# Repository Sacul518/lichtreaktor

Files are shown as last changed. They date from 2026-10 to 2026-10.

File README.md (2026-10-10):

# Lichtreaktor

I'm designing a small, round arc-reactor lookalike that produces light in cool patterns. The plan is to press the rotary encoder to switch patterns, and turn it to control the brightness.

The PCB is 90 mm across, with 24 blue LEDs around the edge, a knob in the middle and a XIAO near the top for USB-C access. Six groups of four LEDs will be controlled independently. Tiny reactor, zero fusion involved.

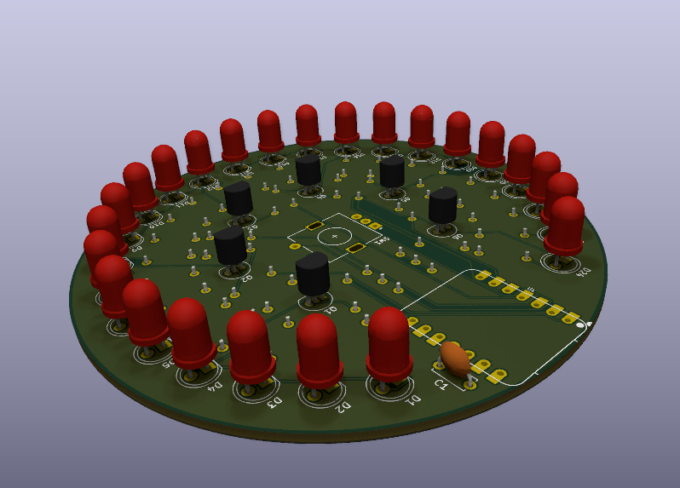
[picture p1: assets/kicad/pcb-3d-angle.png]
Angled view of the Lichtreaktor PCB in KiCad's 3D viewer


The LEDs look red in KiCad's default 3D model, but the actual parts are blue. The XIAO and rotary encoder don't have 3D models loaded, so their positions look empty here.

## Where it's at

The schematic and PCB layout are done! All 24 LEDs are placed, the traces are routed, and both copper layers have a GND fill. The LEDs, transistors, encoder and XIAO sit on the front; the resistors sit on the back. Getting everything onto a round board took a few attempts, but it fits.

The latest KiCad check (10 October 2026) reports **0 errors, 0 unconnected items and 0 schematic/PCB mismatches**. There are still 24 silkscreen warnings: some printed outlines or labels overlap pads, each other or the board edge. Those are accepted for this layout; parts of the print may be clipped during manufacturing. The USB connector intentionally sticks out a little at the top.

This is still a design, not a tested reactor. The [firmware](firmware/README.md) is written, with five light patterns, encoder controls, adjustable speed, a group test and USB diagnostics. Final part and mechanical checks, supplier prices, fabrication files, soldering and testing on the actual board are next.

## How it works

USB supplies 5 V through the XIAO. Each LED has its own 220 Ω resistor, and each group of four shares a BC337 transistor that switches its connection to GND. The XIAO drives the six transistors through 470 Ω base resistors; 100 kΩ pull-downs keep them off when the control pins aren't being driven. PWM will let the firmware dim each group separately.

The encoder has two rotation signals and a push button, with three 10 kΩ pull-ups to 3.3 V. Turning it will change the brightness, and pressing it will change the pattern. The GND fills keep clearance from the other nets and use thermal reliefs so the pads are easier to hand-solder.

## What will I need to build this?

- Seeed Studio XIAO RP2040 (same one I used for my super cool and sick Hackpad)
- 24 blue LEDs (WP7113QBD/D) (ChatGPT's favourites)
- 24 LED resistors (220 Ω, 1/4 W), one per LED
- A PCB (self-designed ofc)
- 6 BC337 NPN transistors, one per group of four LEDs
- 6 transistor base resistors (470 Ω, 1/4 W)
- 6 transistor pull-down resistors (100 kΩ, 1/4 W)
- Alps Alpine EC11E18244A5 rotary encoder with push button
- 3 encoder pull-up resistors (10 kΩ, 1/4 W)
- 100 nF ceramic capacitor (at least 25 V)
- 2 seven-pin female headers (2.54 mm pitch) for the XIAO
- 2 matching male headers, if the XIAO doesn't already have them
- USB cable for power and programming through the XIAO's USB-C port

[Design BOM with KiCad symbols and footprints](bom.csv). Exact resistor, capacitor and header parts, supplier prices and final mechanical checks are still pending.

## Why these LED coordinates?

The numbers aren't random, even if typing them into KiCad feels a bit like it. The board has a 45 mm radius; the LED centres follow a smaller circle with a 38 mm radius. Its centre is at $(x_c,y_c)=(185,65)\,\mathrm{mm}$ in the PCB editor, right on the encoder shaft.

The planned ring starts 30 degrees clockwise from the top, with 13 degrees between neighbouring LEDs. For LED number $n$, from 1 to 24:

$$
\theta_n = 30^\circ + (n-1)\cdot 13^\circ
$$

The last LED lands at 329 degrees. That leaves a 61-degree gap across the top for the XIAO and USB connection. These angles are layout choices; the circle formula gives the coordinates from them.

KiCad's Y coordinate increases downwards. Measuring the angle clockwise from the top gives:

$$
x_{\mathrm{centre},n}=185\,\mathrm{mm}+38\,\mathrm{mm}\cdot\sin(\theta_n)
$$

$$
y_{\mathrm{centre},n}=65\,\mathrm{mm}-38\,\mathrm{mm}\cdot\cos(\theta_n)
$$

One small catch: the `LED_THT:LED_D5.0mm` footprint is anchored on pad 1, with the LED centre 1.27 mm to its right at 0-degree rotation. So the positions entered in KiCad are:

$$
x_{\mathrm{KiCad},n}=x_{\mathrm{centre},n}-1.27\,\mathrm{mm},\qquad
y_{\mathrm{KiCad},n}=y_{\mathrm{centre},n}
$$

For D1, $\theta_1=30^\circ$, which gives:

$$
x_{\mathrm{KiCad},1}=185+38\sin(30^\circ)-1.27=202.73\,\mathrm{mm}
$$

$$
y_{\mathrm{KiCad},1}=65-38\cos(30^\circ)\approx32.09\,\mathrm{mm}
$$

All LEDs use 0-degree rotation for this calculation, and coordinates are rounded to 0.01 mm. Neighbouring LED centres are about $2\cdot38\sin(13^\circ/2)=8.60\,\mathrm{mm}$ apart. Some resistor positions were adjusted by hand to avoid overlaps; the final layout passes KiCad's copper-clearance and courtyard checks.

## Design files

Open [the KiCad project](hardware/Lichtreaktor/Lichtreaktor.kicad_pro) to see the schematic and PCB. The project includes its XIAO symbol and footprint libraries; their source and adaptations are documented [here](hardware/Lichtreaktor/libraries/SOURCES.md).

## A closer look

### PCB layout

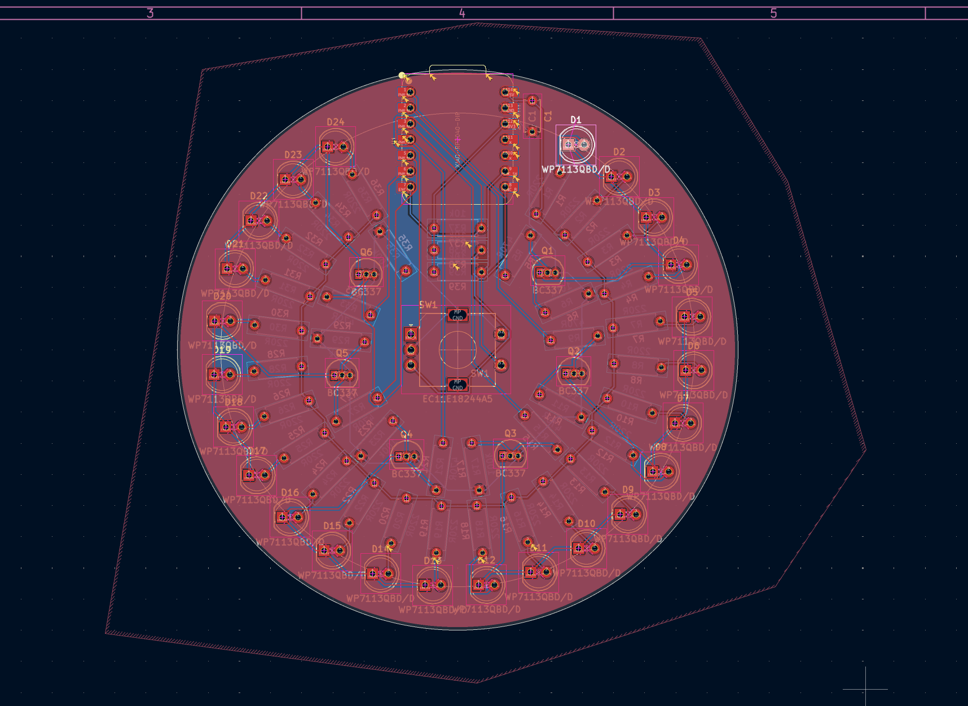
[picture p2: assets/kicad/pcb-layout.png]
Routed PCB layout with GND fills in KiCad


### Front and back

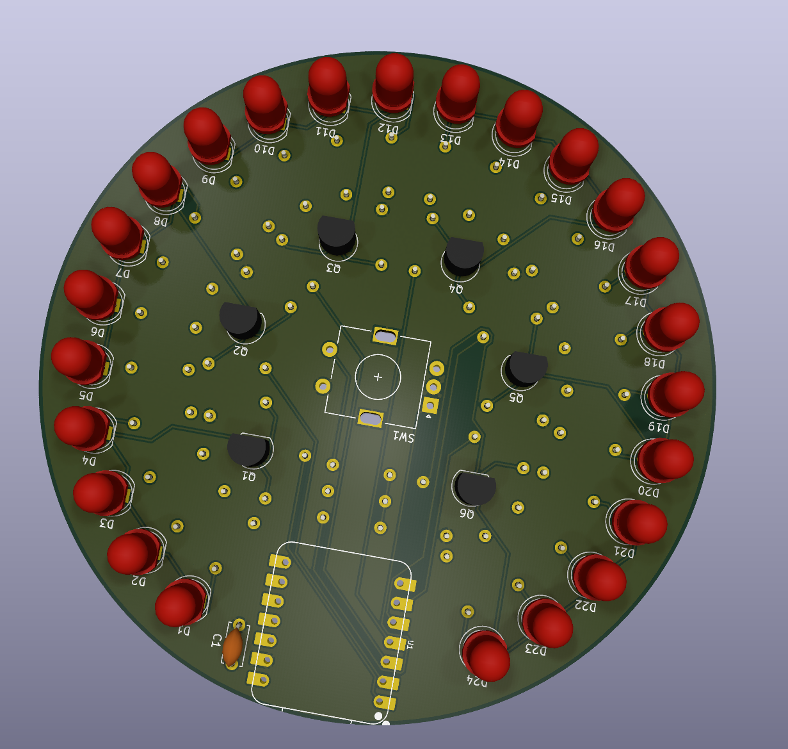
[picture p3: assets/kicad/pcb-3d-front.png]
Front of the PCB in KiCad's 3D viewer


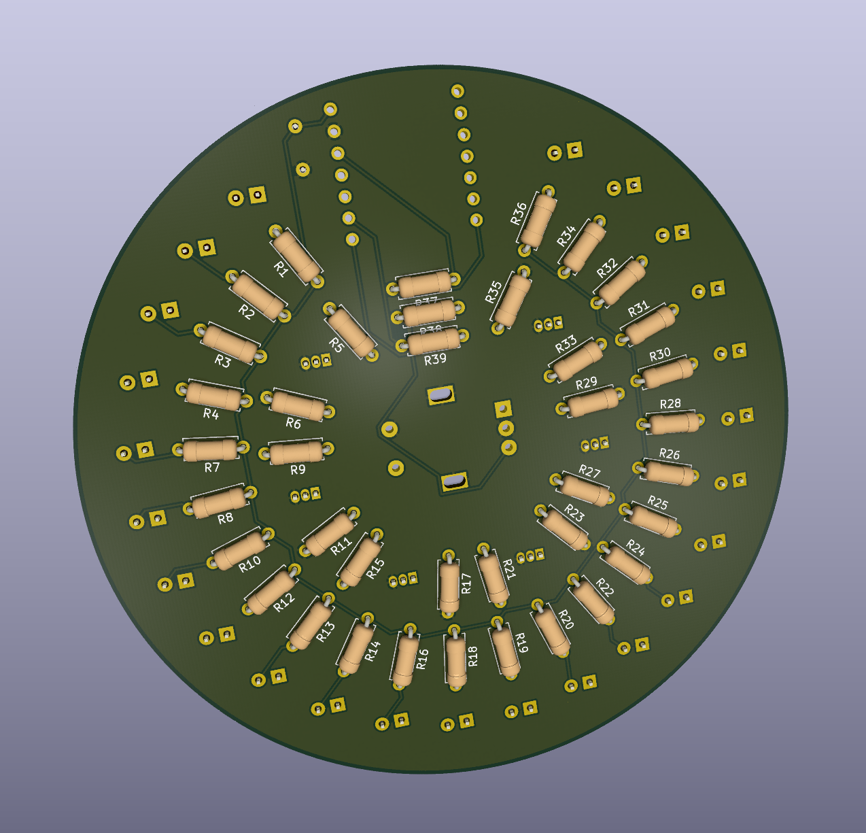
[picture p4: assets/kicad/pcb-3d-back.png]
Back of the PCB with the resistors in KiCad's 3D viewer


### Schematic

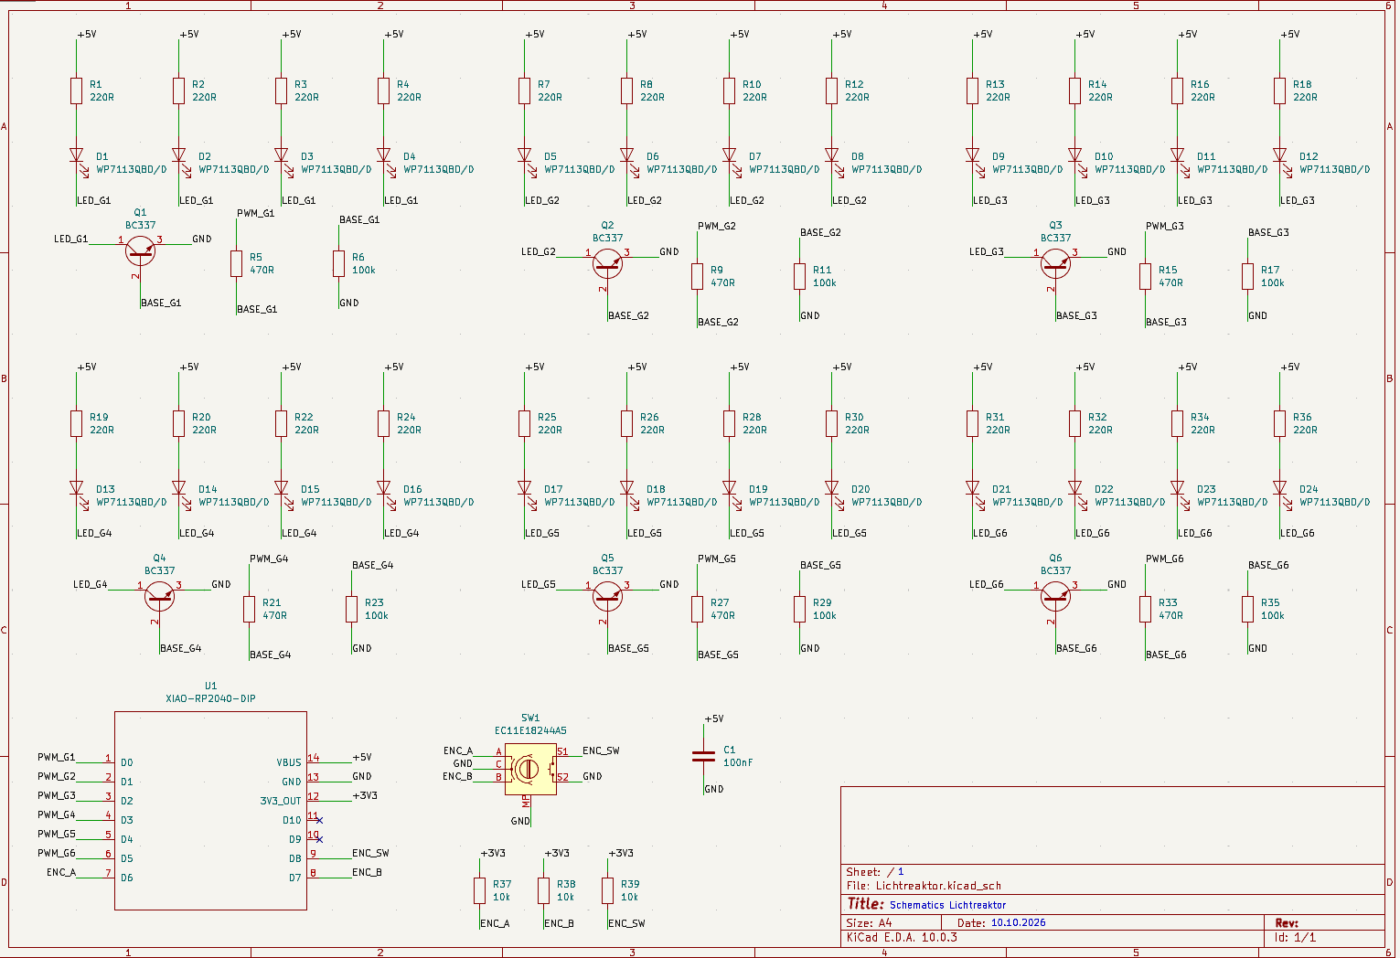
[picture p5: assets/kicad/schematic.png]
Complete Lichtreaktor schematic with six LED groups and the XIAO RP2040


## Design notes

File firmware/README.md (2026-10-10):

# Lichtreaktor firmware

Arduino C++ for the **Seeed XIAO RP2040**, using Earle Philhower's **Arduino-Pico 6.3.0** core. No additional libraries are required.

## Controls

- Turn the encoder to change brightness in steps of 8, from 0 (off) to 255.
- Press and release to cycle through steady light, breathing, a rotating trail, alternating groups and a double pulse.
- Hold and turn to change effect speed from 25% to 300% in steps of 25%. A speed change restarts the current effect. Release without changing the pattern.
- Hold for 1.2 seconds without turning to enter or leave the LED group test. In the test, turning selects one of the six groups; a short press leaves the test. Brightness is retained, so turn it up before entering if it is currently zero.
- Starts in steady mode at brightness 80/255. Settings reset when power is removed.

The encoder is polled continuously, the button is debounced for 25 ms, and LED values are recalculated and written on every loop without blocking delays. PWM runs at 2 kHz. All LEDs within a group share the same output; this board cannot control individual LEDs separately.

## USB diagnostics

Open a serial monitor at 115200 baud. USB serial is optional; the board does not wait for a computer to connect. Commands are single characters, so a newline is not required (and is ignored).

| Command | Action |
| --- | --- |
| `?` | Show command help |
| `s` | Show pattern, brightness, speed, test mode and selected group |
| `n` | Next pattern and leave test mode |
| `+` / `-` | Increase / decrease brightness |
| `>` / `<` | Increase / decrease speed |
| `t` | Toggle the group test, starting at group 1 |
| `1` through `6` | Enter the test and select that LED group |

Pattern and group numbers in the status output start at 1. Only the selected group lights in test mode. For example, send `1`, then `2`, through `6` to check each transistor and its four LEDs. If brightness is zero, use `+` to raise it. `n` returns to an effect. USB processing is limited to eight incoming characters per loop, and pending replies wait for output buffer space.

Codex helped write the firmware; comments in the sketch identify that assistance. Hardware validation is still pending.

## Pin mapping

Arduino-Pico's raw pin numbers are the RP2040 GPIO numbers. They are **not** the D numbers printed on the module.

| PCB signal | XIAO pin | GPIO used in firmware |
| --- | --- | --- |
| PWM_G1 | D0 | 26 |
| PWM_G2 | D1 | 27 |
| PWM_G3 | D2 | 28 |
| PWM_G4 | D3 | 29 |
| PWM_G5 | D4 | 6 |
| PWM_G6 | D5 | 7 |
| ENC_A | D6 | 0 |
| ENC_B | D7 | 1 |
| ENC_SW | D8 | 2 |

The encoder inputs use the PCB's external 10 kΩ pull-ups to 3.3 V. LED outputs are active high because the BC337 transistors switch the groups to GND.

The EC11E18244A5 has 36 detents and 18 pulses per revolution, so `ENCODER_TRANSITIONS_PER_STEP` is 2. For an encoder substitute, check its datasheet. If clockwise rotation dims instead of brightening, change `ENCODER_DIRECTION` from `1` to `-1` and rebuild.

## Build

Install [Arduino CLI](https://docs.arduino.cc/arduino-cli/installation), then run these commands from the repository root:

```sh
arduino-cli core update-index --additional-urls https://github.com/earlephilhower/arduino-pico/releases/download/global/package_rp2040_index.json
arduino-cli core install rp2040:rp2040@6.3.0 --additional-urls https://github.com/earlephilhower/arduino-pico/releases/download/global/package_rp2040_index.json
arduino-cli compile --fqbn rp2040:rp2040:seeed_xiao_rp2040 --warnings all --output-dir firmware/build firmware/lichtreaktor
```

Alternatively, open `lichtreaktor/lichtreaktor.ino` in Arduino IDE, install the same Arduino-Pico core using its package URL, and select **Seeed XIAO RP2040**. Do not select the Plus or RP2350 board.

The build produces `build/lichtreaktor.ino.uf2`. To flash it, connect the XIAO by USB while holding **BOOT**, then copy that UF2 onto the **RPI-RP2** drive. This replaces its existing firmware. On a Mac, from the repository root:

```sh
cp -X firmware/build/lichtreaktor.ino.uf2 /Volumes/RPI-RP2/
```

The drive should disappear and the firmware should start. The build command does not flash a board.

## Verification

A successful build does **not** verify the assembled board. On first hardware bring-up, check each group, encoder direction and detent count, button operation, and brightness at both limits. The 2 kHz electrical PWM and the physical LED behaviour have not been measured yet.

## References

- [Seeed XIAO RP2040 pinout and getting started](https://wiki.seeedstudio.com/XIAO-RP2040/)
- [Arduino-Pico installation](https://arduino-pico.readthedocs.io/en/latest/install.html)
- [Arduino-Pico PWM API](https://arduino-pico.readthedocs.io/en/latest/analog.html)
- [Alps EC11E series specifications, including EC11E18244A5](https://tech.alpsalpine.com/e/products/category/encorders/sub/01/series/ec11e/)

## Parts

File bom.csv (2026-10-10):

References | Quantity | Value | Description | KiCad_Symbol | Footprint | Manufacturer | MPN | Datasheet_URL | Notes | Status | Unit_Price_EUR | Supplier_URL
U1 | 1 | XIAO RP2040 | Controller module with USB-C | Seeed_XIAO:XIAO-RP2040-DIP | Seeed_XIAO:XIAO-RP2040-DIP | Seeed Studio | 102010428 | https://wiki.seeedstudio.com/XIAO-RP2040/ | Project symbol adapted from official Seeed symbol for the 14 side pins. Official DIP footprint with unavailable 3D references removed. See hardware/Lichtreaktor/libraries/SOURCES.md. | Design selection; price pending
MODULE_SOCKETS | 2 | Socket 1x07 2.54mm | Female socket for XIAO module |  |  |  |  |  | Purchased mounting parts; already represented by the module DIP footprint, not additional schematic symbols. Rows 15.24mm apart. Check socket height and USB clearance before ordering. | Mechanical part selection pending
MODULE_HEADERS | 2 | Header 1x07 2.54mm | Male header fitted to XIAO module |  |  |  |  |  | Only needed if module does not already include soldered headers. Not an extra component in the carrier schematic. | Check module contents
D1, D2, D3, D4, D5, D6, D7, D8, D9, D10, D11, D12, D13, D14, D15, D16, D17, D18, D19, D20, D21, D22, D23, D24 | 24 | WP7113QBD/D | Blue diffuse 5mm LED | Device:LED | LED_THT:LED_D5.0mm | Kingbright | WP7113QBD/D | https://www.kingbrightusa.com/images/catalog/SPEC/WP7113QBD-D.pdf | Six groups of four parallel branches. Each LED has its own 220 ohm series resistor. Symbol pin 1=K (cathode); pin 2=A (anode). | Design selection; price pending
R1, R2, R3, R4, R7, R8, R10, R12, R13, R14, R16, R18, R19, R20, R22, R24, R25, R26, R28, R30, R31, R32, R34, R36 | 24 | 220R | LED current-limiting resistor; 0.25W; 1% | Device:R | Resistor_THT:R_Axial_DIN0207_L6.3mm_D2.5mm_P7.62mm_Horizontal |  |  |  | One resistor per LED. Nominal estimate: (5V - 3.3V - 0.2V) / 220 ohm = 6.8mA. Actual current depends on LED and transistor. Select body approximately 6.3 x 2.5mm. | Exact part and price pending
Q1, Q2, Q3, Q4, Q5, Q6 | 6 | BC337 | NPN transistor switching one LED group to ground | Transistor_BJT:BC337 | Package_TO_SOT_THT:TO-92_Inline | onsemi | BC33725BU | https://www.onsemi.com/pdf/datasheet/bc337-fsc-d.pdf | Straight-lead BU package. Pin 1=collector; 2=base; 3=emitter. Use 470 ohm from GPIO to base and 100k from base to emitter. Do not substitute a transistor without checking pinout. | Design selection; price pending
R5, R9, R15, R21, R27, R33 | 6 | 470R | Transistor base resistor; 0.25W; 1% | Device:R | Resistor_THT:R_Axial_DIN0207_L6.3mm_D2.5mm_P7.62mm_Horizontal |  |  |  | Limits GPIO current into transistor base. About (3.3V - 0.8V) / 470 ohm = 5.3mA per enabled group. Confirm GPIO drive configuration in firmware. | Exact part and price pending
R6, R11, R17, R23, R29, R35 | 6 | 100k | Transistor base pull-down resistor; 0.25W; 1% | Device:R | Resistor_THT:R_Axial_DIN0207_L6.3mm_D2.5mm_P7.62mm_Horizontal |  |  |  | One between base and emitter of each transistor. Keeps LEDs off while GPIO is not driven during boot/reset. | Exact part and price pending
SW1 | 1 | EC11E18244A5 | Rotary encoder with momentary push switch | Device:RotaryEncoder_Switch_MP | Rotary_Encoder:RotaryEncoder_Alps_EC11E-Switch_Vertical_H20mm | Alps Alpine | EC11E18244A5 | https://tech.alpsalpine.com/e/products/detail/EC11E18244A5/ | 18 pulses; 36 detents; 20mm flat shaft. Encoder common and one switch contact to GND. A/B and other switch contact to GPIO with 3.3V pull-ups. Software debouncing required. Final dimensions must be compared with selected part drawing before PCB release. | Design selection; mechanical check and price pending
R37, R38, R39 | 3 | 10k | Encoder A/B and push-switch pull-up; 0.25W; 1% | Device:R | Resistor_THT:R_Axial_DIN0207_L6.3mm_D2.5mm_P7.62mm_Horizontal |  |  |  | One from each of encoder A/B and switch GPIO to 3V3. Never pull these GPIO signals up to 5V. | Exact part and price pending
C1 | 1 | 100nF | Ceramic supply decoupling capacitor; >=25V | Device:C | Capacitor_THT:C_Disc_D5.0mm_W2.5mm_P5.00mm |  |  |  | Between +5V and GND near LED supply distribution. Select 5mm lead pitch and body fitting this footprint. XIAO already has onboard regulator decoupling. | Exact part and price pending
PCB | 1 | Lichtreaktor carrier | Custom two-layer PCB |  |  |  |  |  | Round two-layer PCB; 90mm diameter (45mm radius). LED centre ring radius 38mm. Placement in progress; not routed or fabrication-ready. USB power through XIAO only; no battery or separate power input. | Layout and fabrication quote pending

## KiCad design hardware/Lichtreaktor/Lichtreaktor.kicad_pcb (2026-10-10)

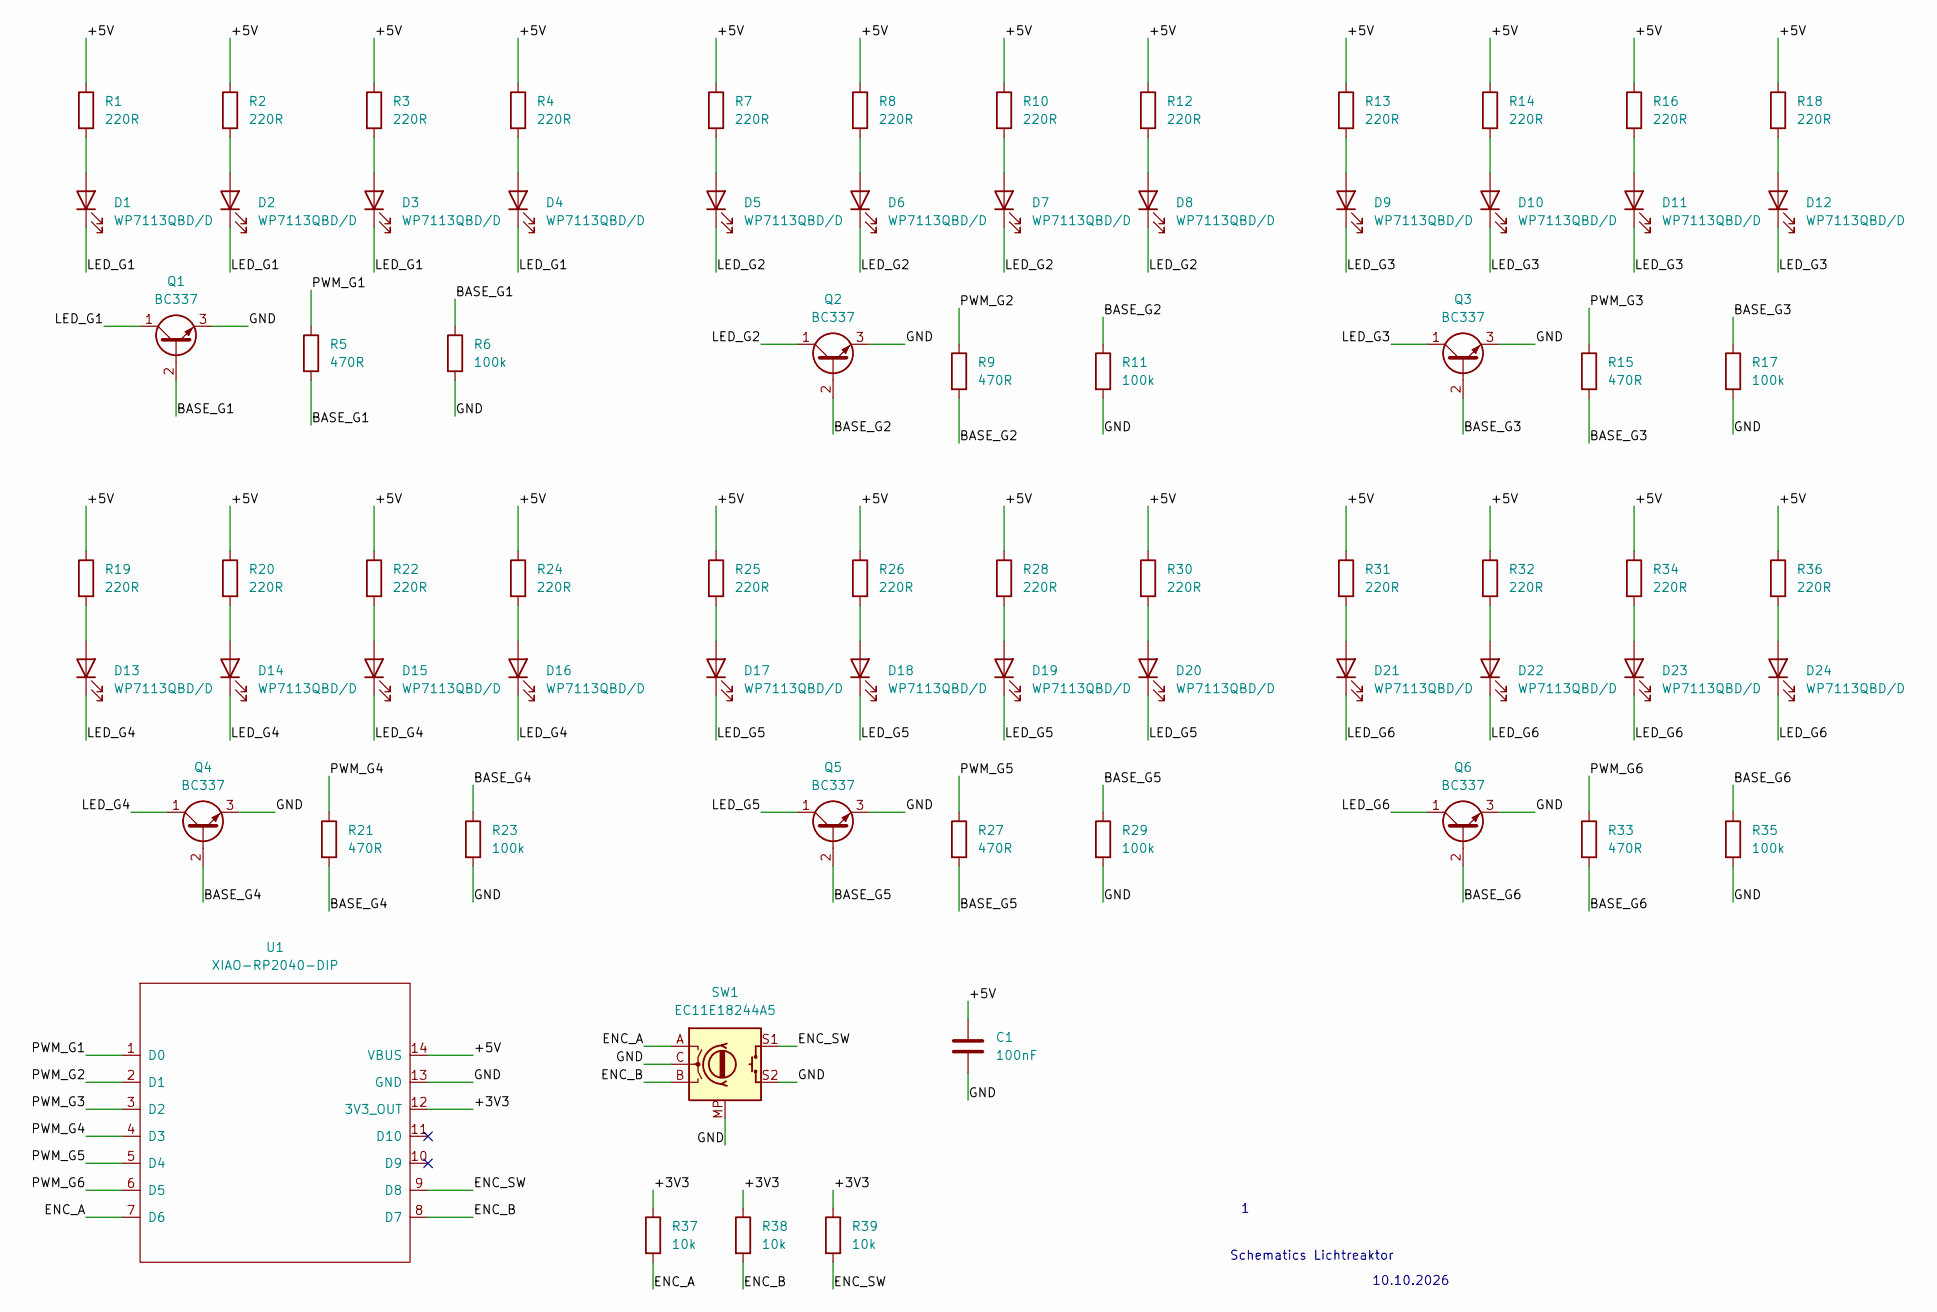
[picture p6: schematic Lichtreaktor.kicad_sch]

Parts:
C1: 100nF; C_Disc_D5.0mm_W2.5mm_P5.00mm
D1, D2, D3, D4, D5, D6, D7, D8, D9, D10, D11, D12, D13, D14, D15, D16, D17, D18, D19, D20, D21, D22, D23, D24: WP7113QBD/D; LED_D5.0mm
Q1, Q2, Q3, Q4, Q5, Q6: BC337; TO-92_Inline
R1, R2, R3, R4, R7, R8, R10, R12, R13, R14, R16, R18, R19, R20, R22, R24, R25, R26, R28, R30, R31, R32, R34, R36: 220R; R_Axial_DIN0207_L6.3mm_D2.5mm_P7.62mm_Horizontal
R5, R9, R15, R21, R27, R33: 470R; R_Axial_DIN0207_L6.3mm_D2.5mm_P7.62mm_Horizontal
R6, R11, R17, R23, R29, R35: 100k; R_Axial_DIN0207_L6.3mm_D2.5mm_P7.62mm_Horizontal
R37, R38, R39: 10k; R_Axial_DIN0207_L6.3mm_D2.5mm_P7.62mm_Horizontal
SW1: EC11E18244A5; RotaryEncoder_Alps_EC11E-Switch_Vertical_H20mm
U1: XIAO-RP2040-DIP

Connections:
/+3V3: R37.1, R38.1, R39.1, U1.12 (3V3_OUT)
/+5V: C1.1, R1.1, R2.1, R3.1, R4.1, R7.1, R8.1, R10.1, R12.1, R13.1, R14.1, R16.1, R18.1, R19.1, R20.1, R22.1, R24.1, R25.1, R26.1, R28.1, R30.1, R31.1, R32.1, R34.1, R36.1, U1.14 (VBUS)
/BASE_G1: Q1.2 (B), R5.2, R6.1
/BASE_G2: Q2.2 (B), R9.2, R11.1
/BASE_G3: Q3.2 (B), R15.2, R17.1
/BASE_G4: Q4.2 (B), R21.2, R23.1
/BASE_G5: Q5.2 (B), R27.2, R29.1
/BASE_G6: Q6.2 (B), R33.2, R35.1
/ENC_A: R37.2, SW1.A, U1.7 (D6)
/ENC_B: R38.2, SW1.B, U1.8 (D7)
/ENC_SW: R39.2, SW1.S1, U1.9 (D8)
/GND: C1.2, Q1.3 (E), Q2.3 (E), Q3.3 (E), Q4.3 (E), Q5.3 (E), Q6.3 (E), R6.2, R11.2, R17.2, R23.2, R29.2, R35.2, SW1.C, SW1.MP, SW1.S2, U1.13 (GND)
/LED_G1: D1.1 (K), D2.1 (K), D3.1 (K), D4.1 (K), Q1.1 (C)
/LED_G2: D5.1 (K), D6.1 (K), D7.1 (K), D8.1 (K), Q2.1 (C)
/LED_G3: D9.1 (K), D10.1 (K), D11.1 (K), D12.1 (K), Q3.1 (C)
/LED_G4: D13.1 (K), D14.1 (K), D15.1 (K), D16.1 (K), Q4.1 (C)
/LED_G5: D17.1 (K), D18.1 (K), D19.1 (K), D20.1 (K), Q5.1 (C)
/LED_G6: D21.1 (K), D22.1 (K), D23.1 (K), D24.1 (K), Q6.1 (C)
/PWM_G1: R5.1, U1.1 (D0)
/PWM_G2: R9.1, U1.2 (D1)
/PWM_G3: R15.1, U1.3 (D2)
/PWM_G4: R21.1, U1.4 (D3)
/PWM_G5: R27.1, U1.5 (D4)
/PWM_G6: R33.1, U1.6 (D5)
unnamed: D1.2 (A), R1.2
unnamed: D2.2 (A), R2.2
unnamed: D3.2 (A), R3.2
unnamed: D4.2 (A), R4.2
unnamed: D5.2 (A), R7.2
unnamed: D6.2 (A), R8.2
unnamed: D7.2 (A), R10.2
unnamed: D8.2 (A), R12.2
unnamed: D9.2 (A), R13.2
unnamed: D10.2 (A), R14.2
unnamed: D11.2 (A), R16.2
unnamed: D12.2 (A), R18.2
unnamed: D13.2 (A), R19.2
unnamed: D14.2 (A), R20.2
unnamed: D15.2 (A), R22.2
unnamed: D16.2 (A), R24.2
unnamed: D17.2 (A), R25.2
unnamed: D18.2 (A), R26.2
unnamed: D19.2 (A), R28.2
unnamed: D20.2 (A), R30.2
unnamed: D21.2 (A), R31.2
unnamed: D22.2 (A), R32.2
unnamed: D23.2 (A), R34.2
unnamed: D24.2 (A), R36.2

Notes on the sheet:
10.10.2026
Schematics Lichtreaktor

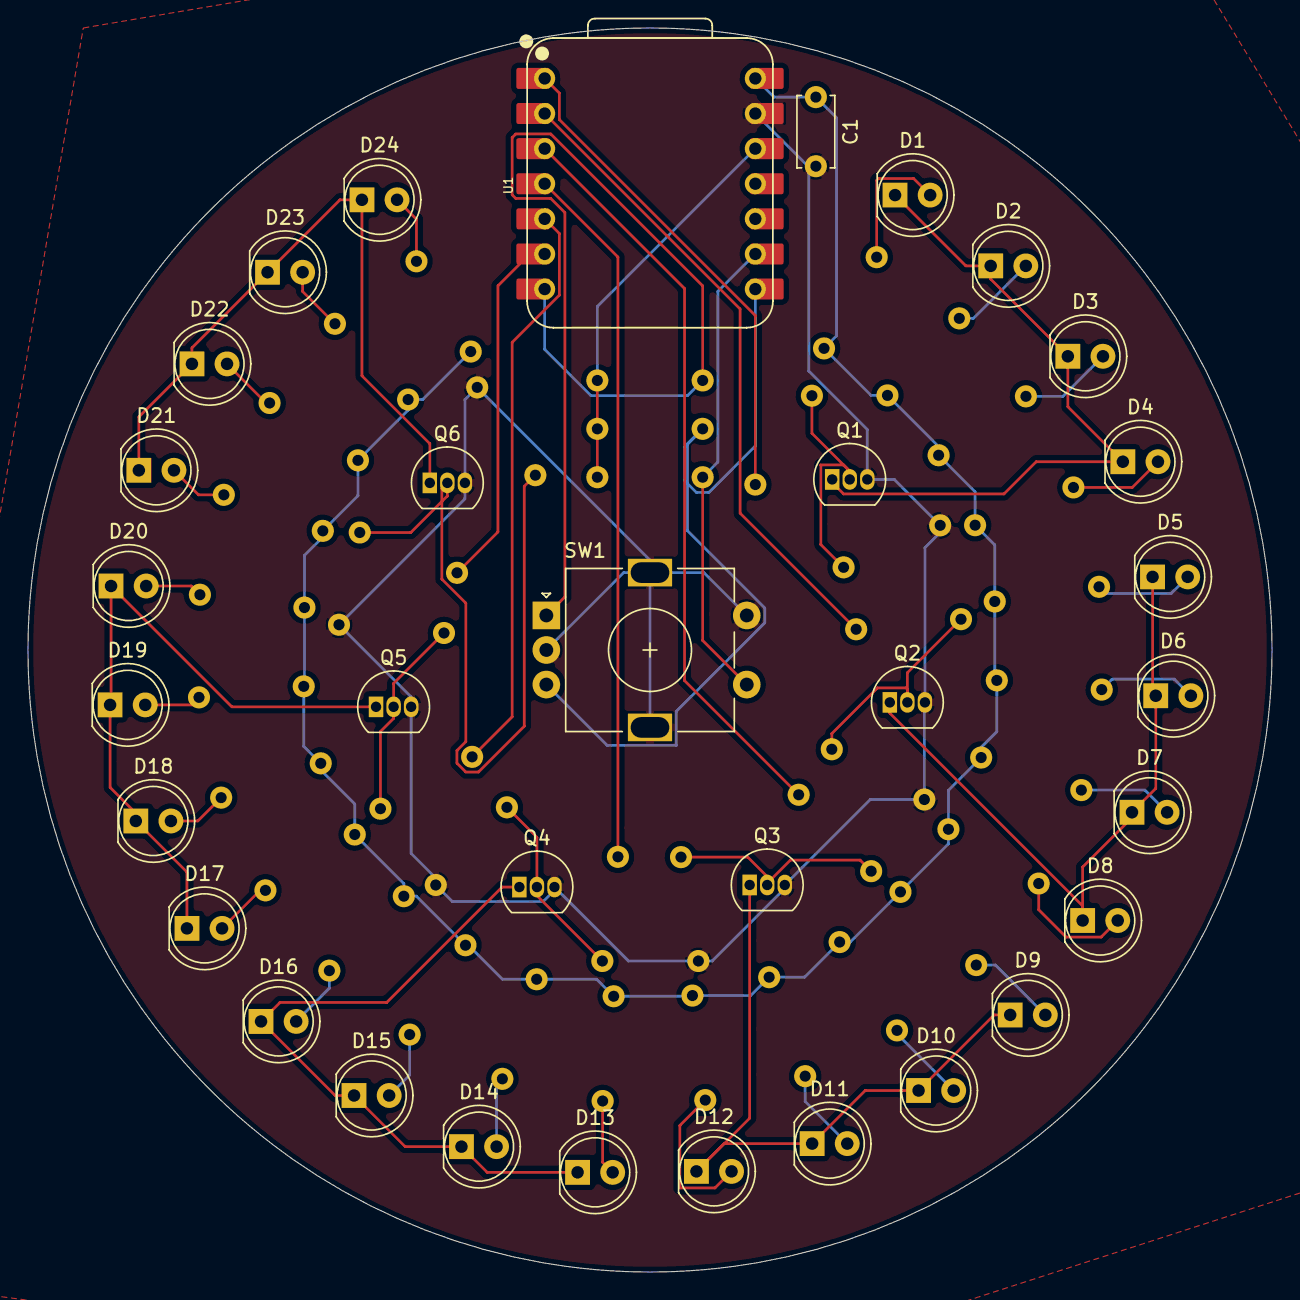
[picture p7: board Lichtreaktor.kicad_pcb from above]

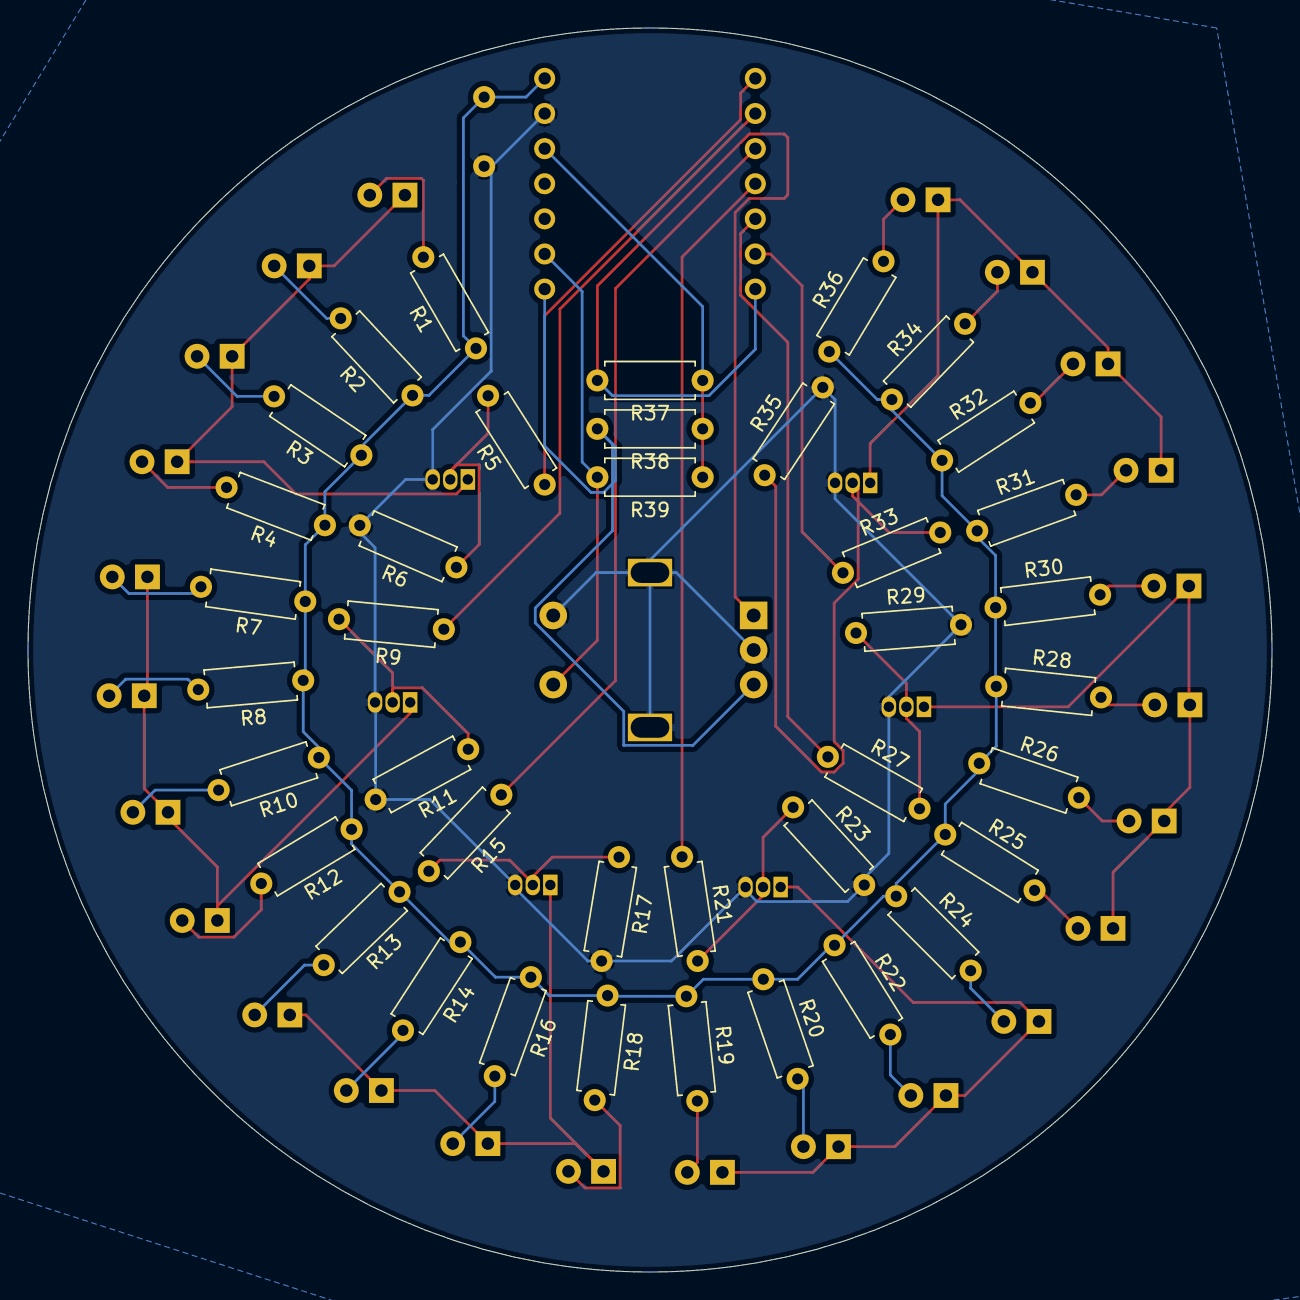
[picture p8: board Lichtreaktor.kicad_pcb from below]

Board: 2 copper layers, 90.0 x 90.0 mm, 72 parts (39 on the bottom side), 48 nets.

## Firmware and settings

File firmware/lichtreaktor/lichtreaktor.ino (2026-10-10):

#include <Arduino.h>
#include <stdio.h>
#include <string.h>

// Codex helped write this firmware, including the encoder decoder. but I did most of the heavy lifting.
// Encoder direction and LED behaviour still need checking on the assembled PCB.

// Arduino-Pico uses RP2040 GPIO numbers, not the numbers printed after D.
constexpr uint8_t LED_PINS[] = {26, 27, 28, 29, 6, 7}; // D0–D5, groups 1–6
constexpr uint8_t ENCODER_A_PIN = 0;                  // D6
constexpr uint8_t ENCODER_B_PIN = 1;                  // D7
constexpr uint8_t ENCODER_BUTTON_PIN = 2;             // D8
constexpr int8_t ENCODER_DIRECTION = 1;
// EC11E18244A5: 36 dtents / 18 pulses, two transitions per detent.
constexpr int8_t ENCODER_TRANSITIONS_PER_STEP = 2;
constexpr uint8_t GROUP_COUNT = 6;
constexpr uint8_t PATTERN_COUNT = 5;
constexpr uint8_t BRIGHTNESS_STEP = 8;
constexpr uint32_t BUTTON_DEBOUNCE_MS = 25;
constexpr uint32_t LONG_PRESS_MS = 1200;
constexpr uint16_t MIN_SPEED_PERCENT = 25;
constexpr uint16_t MAX_SPEED_PERCENT = 300;
constexpr uint16_t SPEED_STEP = 25;

uint8_t brightness = 80;
uint8_t pattern = 0;
uint8_t encoderState = 0;
int8_t encoderTransitions = 0;
bool buttonRaw = false;
bool buttonStable = false;
uint32_t buttonChangedAt = 0;
uint32_t patternStartedAt = 0;
uint16_t speedPercent = 100;
bool testMode = false;
uint8_t testGroup = 0;
bool buttonUsedForAdjustment = false;
bool buttonLongHandled = false;
uint32_t buttonPressedAt = 0;
bool statusPending = true;
bool helpPending = false;
bool serialWasConnected = false;

void changeBrightness(int direction) {
  const int value = brightness + direction * BRIGHTNESS_STEP;
  if (value < 0) {
    brightness = 0;
  } else if (value > 255) {
    brightness = 255;
  } else {
    brightness = value;
  }
  statusPending = true;
}

void changeSpeed(int direction, uint32_t now) {
  const int value = speedPercent + direction * SPEED_STEP;
  if (value < MIN_SPEED_PERCENT) {
    speedPercent = MIN_SPEED_PERCENT;
  } else if (value > MAX_SPEED_PERCENT) {
    speedPercent = MAX_SPEED_PERCENT;
  } else {
    speedPercent = value;
  }
  // Speed changes restart the effect at a predictabel phase.
  patternStartedAt = now;
  statusPending = true;
}

void nextPattern(uint32_t now) {
  pattern = pattern + 1;
  if (pattern >= PATTERN_COUNT) {
    pattern = 0;
  }
  patternStartedAt = now;
  testMode = false;
  statusPending = true;
}

void toggleTestMode(uint32_t now) {
  testMode = !testMode;
  testGroup = 0;
  patternStartedAt = now;
  statusPending = true;
}

void encoderStep(int direction, uint32_t now) {
  if (buttonStable) buttonUsedForAdjustment = true;
  if (testMode) {
    int newGroup = testGroup + direction;
    if (newGroup < 0) {
      newGroup = GROUP_COUNT - 1;
    }
    if (newGroup >= GROUP_COUNT) {
      newGroup = 0;
    }
    testGroup = newGroup;
    statusPending = true;
  } else if (buttonStable) {
    changeSpeed(direction, now);
  } else {
    changeBrightness(direction);
  }
}

uint8_t readEncoder() {
  int state = 0;
  if (digitalRead(ENCODER_A_PIN) == HIGH) {
    state = state + 2;
  }
  if (digitalRead(ENCODER_B_PIN) == HIGH) {
    state = state + 1;
  }
  return state;
}

void pollEncoder(uint32_t now) {
  const uint8_t next = readEncoder();
  if (next == encoderState) return;

  if ((encoderState == 0 && next == 3) ||
      (encoderState == 3 && next == 0) ||
      (encoderState == 1 && next == 2) ||
      (encoderState == 2 && next == 1)) {
    // Both signals changed: a transition was missed. Start afresh.
    encoderTransitions = 0;
  } else {
    if ((encoderState == 0 && next == 2) ||
        (encoderState == 2 && next == 3) ||
        (encoderState == 3 && next == 1) ||
        (encoderState == 1 && next == 0)) {
      encoderTransitions++;
    } else {
      encoderTransitions--;
    }
    if (encoderTransitions >= ENCODER_TRANSITIONS_PER_STEP ||
        encoderTransitions <= -ENCODER_TRANSITIONS_PER_STEP) {
      int direction = -1;
      if (encoderTransitions > 0) {
        direction = 1;
      }
      encoderStep(direction * ENCODER_DIRECTION, now);
      encoderTransitions = 0;
    }
  }
  encoderState = next;
}

void pollButton(uint32_t now) {
  const bool pressed = digitalRead(ENCODER_BUTTON_PIN) == LOW;
  if (pressed != buttonRaw) {
    buttonRaw = pressed;
    buttonChangedAt = now;
  }
  if (buttonRaw != buttonStable &&
      uint32_t(now - buttonChangedAt) >= BUTTON_DEBOUNCE_MS) {
    buttonStable = buttonRaw;
    if (buttonStable) {
      buttonPressedAt = now;
      buttonUsedForAdjustment = false;
      buttonLongHandled = false;
    } else if (!buttonUsedForAdjustment && !buttonLongHandled) {
      // Wait for release so a speed adjustment does not also change the pattern.
      if (testMode) toggleTestMode(now);
      else nextPattern(now);
    }
  }
  if (buttonStable && buttonRaw && !buttonUsedForAdjustment && !buttonLongHandled &&
      uint32_t(now - buttonPressedAt) >= LONG_PRESS_MS) {
    toggleTestMode(now);
    buttonLongHandled = true;
  }
}

void pollSerial(uint32_t now) {
  const bool connected = bool(Serial);
  if (connected && !serialWasConnected) statusPending = true;
  serialWasConnected = connected;
  if (!connected) return;

  // Limits USB work per loop so pasted commands cannot monopolise encoder polling.
  for (uint8_t count = 0; count < 8 && Serial.available(); ++count) {
    const int command = Serial.read();
    if (command == 's') {
      statusPending = true;
    } else if (command == '?') {
      helpPending = true;
    } else if (command == 't') {
      toggleTestMode(now);
    } else if (command == 'n') {
      nextPattern(now);
    } else if (command == '+') {
      changeBrightness(1);
    } else if (command == '-') {
      changeBrightness(-1);
    } else if (command == '>') {
      changeSpeed(1, now);
    } else if (command == '<') {
      changeSpeed(-1, now);
    } else if (command >= '1' && command <= '6') {
      testMode = true;
      testGroup = command - '1';
      statusPending = true;
    }
  }

  // Keep replies short and wait for USB buffer space rather than blocking LEDs.
  char reply[64];
  if (helpPending) {
    snprintf(reply, sizeof(reply), "s=status t=test n=next 1-6=group +/-=bright </>=speed\n");
  } else if (statusPending) {
    snprintf(reply, sizeof(reply), "mode=%u bright=%u speed=%u%% test=%u group=%u\n",
             unsigned(pattern + 1), unsigned(brightness), unsigned(speedPercent),
             unsigned(testMode), unsigned(testGroup + 1));
  } else {
    return;
  }
  const size_t length = strlen(reply);
  if (Serial.availableForWrite() >= int(length)) {
    Serial.write(reinterpret_cast<const uint8_t *>(reply), length);
    if (helpPending) helpPending = false;
    else statusPending = false;
  }
}

uint8_t patternLevel(uint8_t selected, uint8_t group, uint32_t elapsed) {
  if (selected == 0) {
    return 255;
  }

  if (selected == 1) {
    uint32_t phase = elapsed % 2400;
    uint32_t ramp = 0;
    if (phase < 1200) {
      ramp = phase;
    } else {
      ramp = 2400 - phase;
    }
    uint32_t level = ramp * 255;
    level = level / 1200;
    level = level * level / 255;
    return level;
  }

  if (selected == 2) {
    int head = (elapsed / 160) % GROUP_COUNT;
    int behind = head - group;
    if (behind < 0) {
      behind = behind + GROUP_COUNT;
    }
    if (behind == 0) return 255;
    if (behind == 1) return 70;
    if (behind == 2) return 15;
    return 0;
  }

  if (selected == 3) {
    int groupSide = group % 2;
    int activeSide = (elapsed / 400) % 2;
    if (groupSide == activeSide) {
      return 255;
    }
    return 0;
  }

  if (selected == 4) {
    uint32_t phase = elapsed % 1400;
    if (phase < 120) {
      return 255 - phase * 255 / 120;
    }
    if (phase >= 230 && phase < 400) {
      return (400 - phase) * 255 / 170;
    }
    return 0;
  }

  return 0;
}

void render(uint32_t elapsed) {
  for (uint8_t group = 0; group < GROUP_COUNT; ++group) {
    uint16_t level = 0;
    if (testMode) {
      if (group == testGroup) level = 255;
    } else {
      level = patternLevel(pattern, group, elapsed);
    }
    float output = level;
    output = output * brightness;
    output = output + 127;
    output = output / 255;
    analogWrite(LED_PINS[group], int(output));
  }
}

void setup() {
  Serial.begin(115200);
  // Do not wait for Serial: the reactor must also start from a USB power supply.
  for (uint8_t pin : LED_PINS) {
    digitalWrite(pin, LOW);
    pinMode(pin, OUTPUT);
  }
  analogWriteFreq(2000);
  analogWriteRange(255);

  // External 10 kΩ pull-ups already connect the encoder inputs to 3.3 V.
  pinMode(ENCODER_A_PIN, INPUT);
  pinMode(ENCODER_B_PIN, INPUT);
  pinMode(ENCODER_BUTTON_PIN, INPUT);
  encoderState = readEncoder();
  buttonRaw = digitalRead(ENCODER_BUTTON_PIN) == LOW;
  buttonStable = buttonRaw;
  buttonUsedForAdjustment = buttonStable;
  buttonChangedAt = millis();
  patternStartedAt = buttonChangedAt;
  render(0);
}

void loop() {
  const uint32_t now = millis();
  pollEncoder(now);
  pollButton(now);
  pollSerial(now);
  // Unsigned subtraction also works when millis() wraps around. took me 10min just to figure that out.
  const uint64_t elapsed = uint32_t(now - patternStartedAt);
  render(uint32_t(elapsed * speedPercent / 100));
}

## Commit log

2026-10-10 Add KiCad design, update BOM and document LED ring geometry
    [Lichtreaktor.kicad_pcb, Lichtreaktor.kicad_sch, bom.csv]
2026-10-10 Complete PCB routing and ground pours, update project README
    [Lichtreaktor.kicad_pcb]
2026-10-10 Add firmware, KiCad screenshots and 3D views
